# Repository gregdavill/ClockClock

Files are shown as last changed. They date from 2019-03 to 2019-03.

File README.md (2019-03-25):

# ClockClock

## Experiements with stepper based instrument dials to create a digitally controlled Analoge Clock.

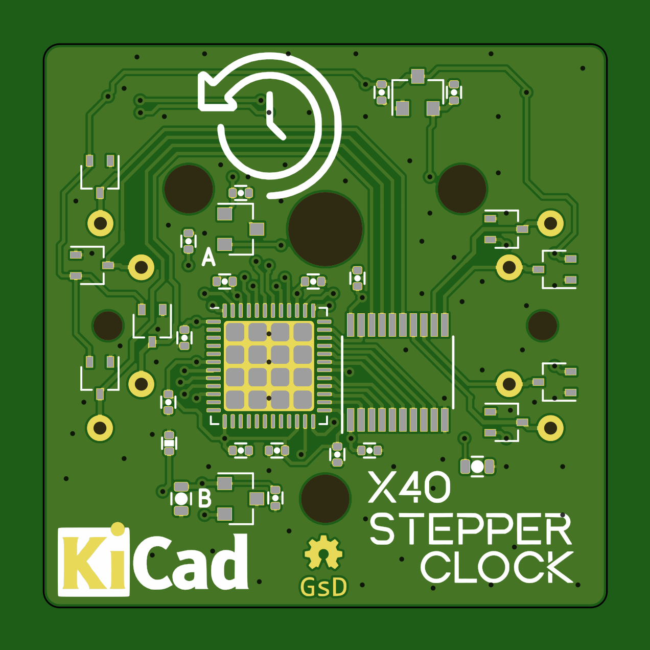
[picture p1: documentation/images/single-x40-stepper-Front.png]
Front View


## Hardware

* MachXo2-640 in QFN48
* Plenty of test pads
* X40 Dual output instument dial stepper (modified for full rotation)
* Hall effect switches for indexing arms on clock
* Flyback diodes on all motor outputs

## Board View

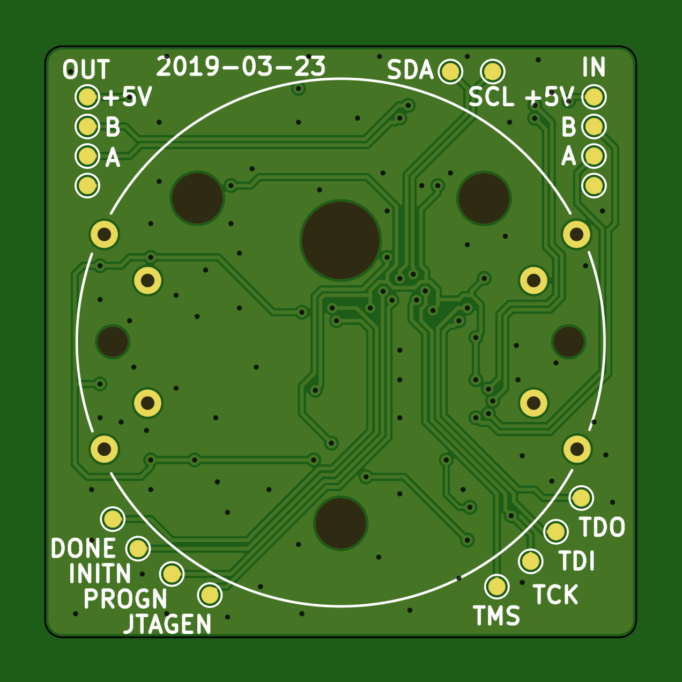
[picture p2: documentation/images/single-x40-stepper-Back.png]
Back View


## Schematic

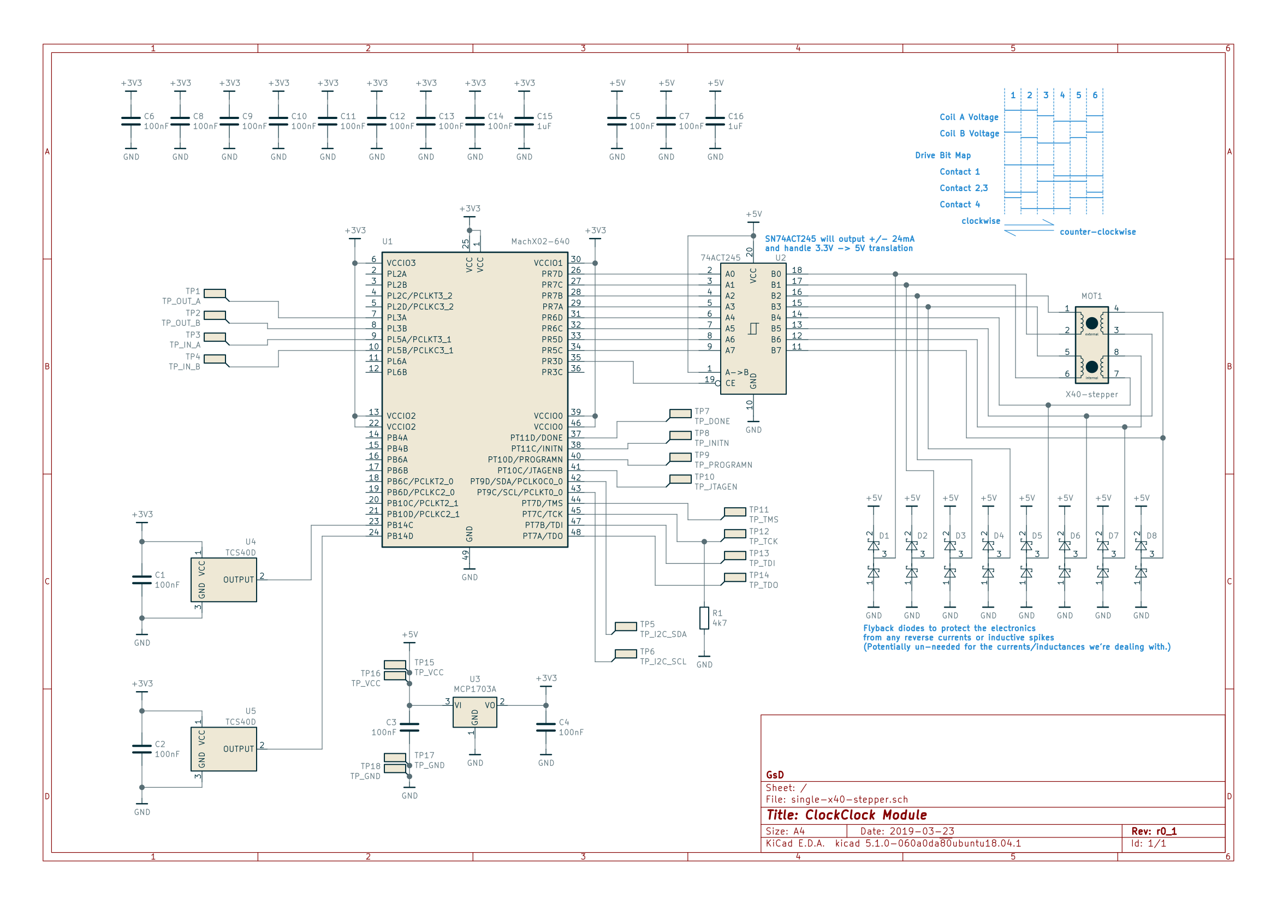
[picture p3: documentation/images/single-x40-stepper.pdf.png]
Schematic


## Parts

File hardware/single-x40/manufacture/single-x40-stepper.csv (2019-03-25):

Source: | /home/greg/projects/ClockClock/hardware/single-x40/single-x40-stepper.sch
Date: | Sat 23 Mar 2019 20:49:43 ACDT
Tool: | Eeschema 5.1.0-060a0da~80~ubuntu18.04.1
Generator: | /usr/share/kicad/plugins/bom_csv_grouped_by_value.py
Component Count: | 31
Individual Components:
Item | Qty | Reference(s) | Value | LibPart | Footprint | Datasheet | Mfg | PN
 |  | C1 | 100nF | Device:C | pkl_dipol:C_0402 | ~ | Samsung Electro-Mechanics | CL05B104KP5NNNC
 |  | C2 | 100nF | Device:C | pkl_dipol:C_0402 | ~ | Samsung Electro-Mechanics | CL05B104KP5NNNC
 |  | C3 | 100nF | Device:C | pkl_dipol:C_0402 | ~ | Samsung Electro-Mechanics | CL05B104KP5NNNC
 |  | C4 | 100nF | Device:C | pkl_dipol:C_0402 | ~ | Samsung Electro-Mechanics | CL05B104KP5NNNC
 |  | C5 | 100nF | Device:C | pkl_dipol:C_0402 | ~ | Samsung Electro-Mechanics | CL05B104KP5NNNC
 |  | C6 | 100nF | Device:C | pkl_dipol:C_0402 | ~ | Samsung Electro-Mechanics | CL05B104KP5NNNC
 |  | C7 | 100nF | Device:C | pkl_dipol:C_0402 | ~ | Samsung Electro-Mechanics | CL05B104KP5NNNC
 |  | C8 | 100nF | Device:C | pkl_dipol:C_0402 | ~ | Samsung Electro-Mechanics | CL05B104KP5NNNC
 |  | C9 | 100nF | Device:C | pkl_dipol:C_0402 | ~ | Samsung Electro-Mechanics | CL05B104KP5NNNC
 |  | C10 | 100nF | Device:C | pkl_dipol:C_0402 | ~ | Samsung Electro-Mechanics | CL05B104KP5NNNC
 |  | C11 | 100nF | Device:C | pkl_dipol:C_0402 | ~ | Samsung Electro-Mechanics | CL05B104KP5NNNC
 |  | C12 | 100nF | Device:C | pkl_dipol:C_0402 | ~ | Samsung Electro-Mechanics | CL05B104KP5NNNC
 |  | C13 | 100nF | Device:C | pkl_dipol:C_0402 | ~ | Samsung Electro-Mechanics | CL05B104KP5NNNC
 |  | C14 | 100nF | Device:C | pkl_dipol:C_0402 | ~ | Samsung Electro-Mechanics | CL05B104KP5NNNC
 |  | C15 | 1uF | Device:C | pkl_dipol:C_0603 | ~ | Samsung Electro-Mechanics | CL10A106MP8NNNC
 |  | C16 | 1uF | Device:C | pkl_dipol:C_0603 | ~ | Samsung Electro-Mechanics | CL10A106MP8NNNC
 |  | D1 | BAT54S | Diode:BAT54S | Package_TO_SOT_SMD:SOT-323_SC-70 | https://www.diodes.com/assets/Datasheets/ds11005.pdf | ON Semiconductor | BAT54SWT1G
 |  | D2 | BAT54S | Diode:BAT54S | Package_TO_SOT_SMD:SOT-323_SC-70 | https://www.diodes.com/assets/Datasheets/ds11005.pdf | ON Semiconductor | BAT54SWT1G
 |  | D3 | BAT54S | Diode:BAT54S | Package_TO_SOT_SMD:SOT-323_SC-70 | https://www.diodes.com/assets/Datasheets/ds11005.pdf | ON Semiconductor | BAT54SWT1G
 |  | D4 | BAT54S | Diode:BAT54S | Package_TO_SOT_SMD:SOT-323_SC-70 | https://www.diodes.com/assets/Datasheets/ds11005.pdf | ON Semiconductor | BAT54SWT1G
 |  | D5 | BAT54S | Diode:BAT54S | Package_TO_SOT_SMD:SOT-323_SC-70 | https://www.diodes.com/assets/Datasheets/ds11005.pdf | ON Semiconductor | BAT54SWT1G
 |  | D6 | BAT54S | Diode:BAT54S | Package_TO_SOT_SMD:SOT-323_SC-70 | https://www.diodes.com/assets/Datasheets/ds11005.pdf | ON Semiconductor | BAT54SWT1G
 |  | D7 | BAT54S | Diode:BAT54S | Package_TO_SOT_SMD:SOT-323_SC-70 | https://www.diodes.com/assets/Datasheets/ds11005.pdf | ON Semiconductor | BAT54SWT1G
 |  | D8 | BAT54S | Diode:BAT54S | Package_TO_SOT_SMD:SOT-323_SC-70 | https://www.diodes.com/assets/Datasheets/ds11005.pdf | ON Semiconductor | BAT54SWT1G
 |  | MOT1 | X40-stepper | gkl_misc:X40-stepper | gkl_misc:X40-stepper
 |  | R1 | 4k7 | Device:R | pkl_dipol:R_0402 | ~ | Stackpole Electronics Inc | RMCF0402FT4K70
 |  | U1 | MachX02-640 | gkl_lattice:MachX02-640 | Package_DFN_QFN:QFN-48-1EP_7x7mm_P0.5mm_EP5.6x5.6mm |  | Lattice Semiconductor Corporation | LCMXO2-640HC-4SG48C
 |  | U2 | 74ACT245 | 74xx:74LS245 | Package_SO:TSSOP-20_4.4x6.5mm_P0.65mm | http://www.ti.com/lit/gpn/sn74LS245 | Texas Instruments | SN74ACT245PWR
 |  | U3 | MCP1703A | Regulator_Linear:MCP1703A-1202_SOT23 | Package_TO_SOT_SMD:SOT-23 | http://ww1.microchip.com/downloads/en/DeviceDoc/20005122B.pdf | Microchip Technology | MCP1703AT-3302E/CB
 |  | U4 | TCS40D | Sensor_Magnetic:SM351LT | Package_TO_SOT_SMD:SOT-23 | https://sensing.honeywell.com/honeywell-sensing-nanopower-series-product-sheet-50095501-a-en.pdf | Toshiba Semiconductor and Storage | TCS40DPR,LF
 |  | U5 | TCS40D | Sensor_Magnetic:SM351LT | Package_TO_SOT_SMD:SOT-23 | https://sensing.honeywell.com/honeywell-sensing-nanopower-series-product-sheet-50095501-a-en.pdf | Toshiba Semiconductor and Storage | TCS40DPR,LF
Collated Components:
Item | Qty | Reference(s) | Value | LibPart | Footprint | Datasheet | Mfg | PN
1 | 14 | C1, C2, C3, C4, C5, C6, C7, C8, C9, C10, C11, C12, C13, C14 | 100nF | Device:C | pkl_dipol:C_0402 | ~ | Samsung Electro-Mechanics | CL05B104KP5NNNC
2 | 2 | C15, C16 | 1uF | Device:C | pkl_dipol:C_0603 | ~ | Samsung Electro-Mechanics | CL10A106MP8NNNC
3 | 8 | D1, D2, D3, D4, D5, D6, D7, D8 | BAT54S | Diode:BAT54S | Package_TO_SOT_SMD:SOT-323_SC-70 | https://www.diodes.com/assets/Datasheets/ds11005.pdf | ON Semiconductor | BAT54SWT1G
4 | 1 | MOT1 | X40-stepper | gkl_misc:X40-stepper | gkl_misc:X40-stepper
5 | 1 | R1 | 4k7 | Device:R | pkl_dipol:R_0402 | ~ | Stackpole Electronics Inc | RMCF0402FT4K70
6 | 1 | U1 | MachX02-640 | gkl_lattice:MachX02-640 | Package_DFN_QFN:QFN-48-1EP_7x7mm_P0.5mm_EP5.6x5.6mm |  | Lattice Semiconductor Corporation | LCMXO2-640HC-4SG48C
7 | 1 | U2 | 74ACT245 | 74xx:74LS245 | Package_SO:TSSOP-20_4.4x6.5mm_P0.65mm | http://www.ti.com/lit/gpn/sn74LS245 | Texas Instruments | SN74ACT245PWR
8 | 1 | U3 | MCP1703A | Regulator_Linear:MCP1703A-1202_SOT23 | Package_TO_SOT_SMD:SOT-23 | http://ww1.microchip.com/downloads/en/DeviceDoc/20005122B.pdf | Microchip Technology | MCP1703AT-3302E/CB
9 | 2 | U4, U5 | TCS40D | Sensor_Magnetic:SM351LT | Package_TO_SOT_SMD:SOT-23 | https://sensing.honeywell.com/honeywell-sensing-nanopower-series-product-sheet-50095501-a-en.pdf | Toshiba Semiconductor and Storage | TCS40DPR,LF

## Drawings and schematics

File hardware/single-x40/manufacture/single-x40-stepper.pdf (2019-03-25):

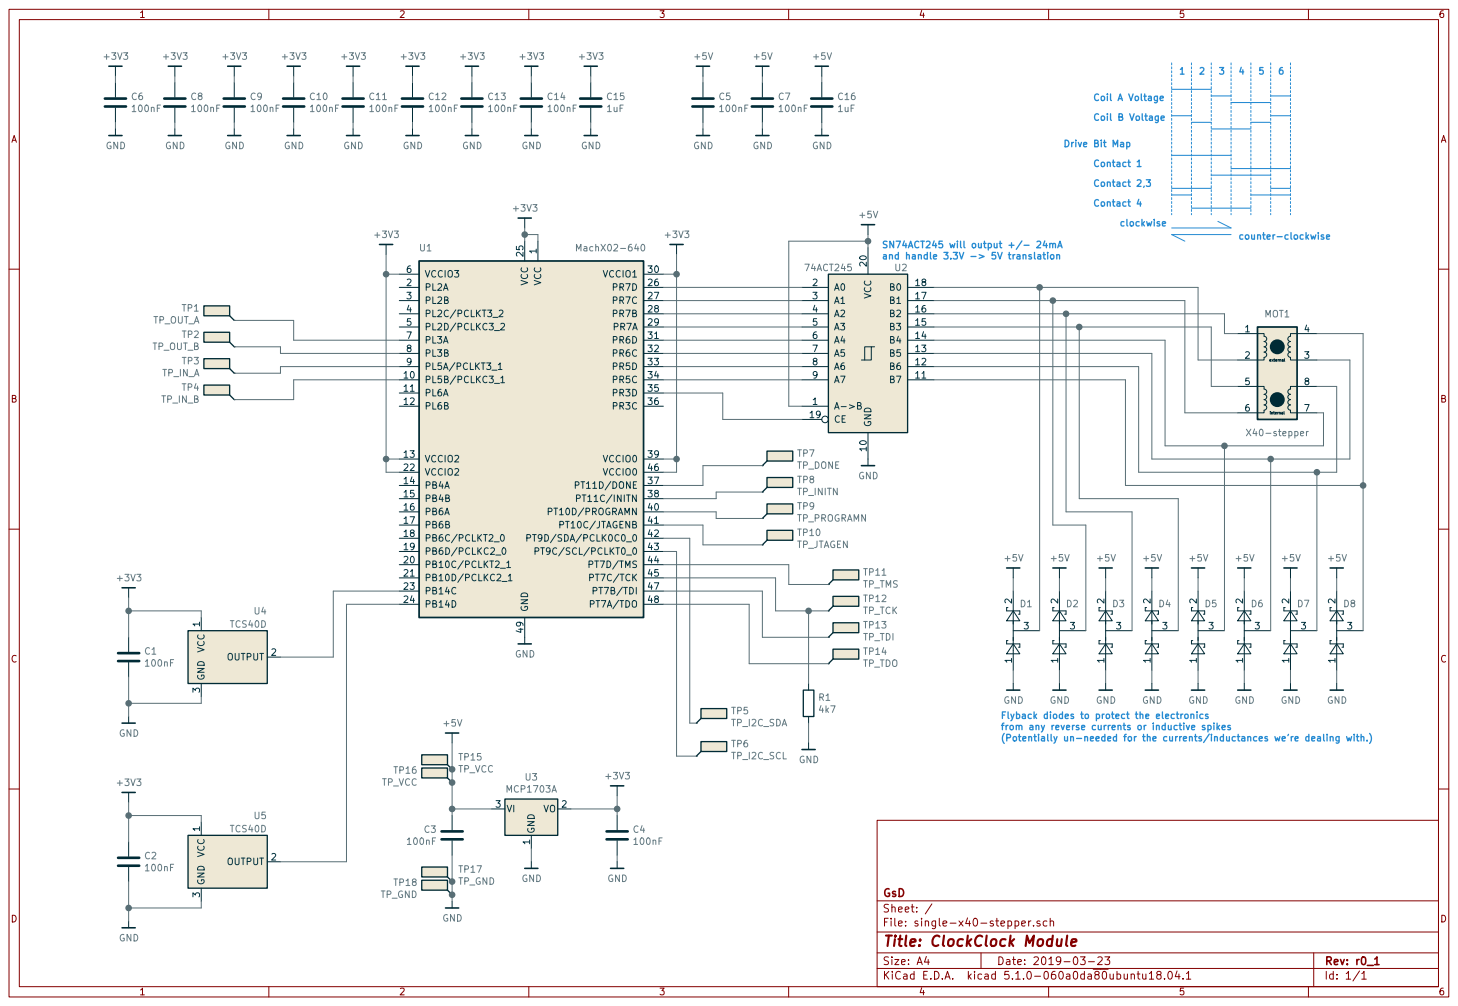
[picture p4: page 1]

Drive Bit Map Contact 1 Contact 2,3 Contact 4

1 PL5B/PCLKC3_1 10 PL6A 11 PL6B 12 VCCIO2 13 PB4A 14 PB4B 15 PB6A 16 PB6B 17 PB6C/PCLKT2_0 18 PB6D/PCLKC2_0 19 PL2A 2 PB10C/PCLKT2_1 20 PB10D/PCLKC2_1 21 VCCIO2 22 PB14C 23 PB14D 24 VCC 25 PR7D 26 PR7C 27 PR7B 28 PR7A 29 PL2B 3 VCCIO1 30 PR6D 31 PR6C 32 PR5D 33 PR5C 34 PR3D 35 PR3C 36 PT11D/DONE 37 PT11C/INITN 38 VCCIO0 39 PL2C/PCLKT3_2 4 PT10D/PROGRAMN 40 PT10C/JTAGENB 41 PT9D/SDA/PCLK0C0_0 42 PT9C/SCL/PCLKT0_0 43 PT7D/TMS 44 PT7C/TCK 45 VCCIO0 46 PT7B/TDI 47 PT7A/TDO 48 GND 49 PL2D/PCLKC3_2 5 VCCIO3 6 PL3A 7 PL3B 8 PL5A/PCLKT3_1 9 U1 MachX02-640 A->B 1 GND 10 B7 11 B6 12 B5 13 B4 14 B3 15 B2 16 B1 17 B0 18 CE 19 A0 2 VCC 20 A1 3 A2 4 A3 5 A4 6 A5 7 A6 8 A7 9

File: single-x40-stepper.sch Sheet: / GsD VCC

(Potentially un-needed for the currents/inductances we're dealing with.) GND

Flyback diodes to protect the electronics
from any reverse currents or inductive spikes

Id: 1/1 Title: ClockClock Module

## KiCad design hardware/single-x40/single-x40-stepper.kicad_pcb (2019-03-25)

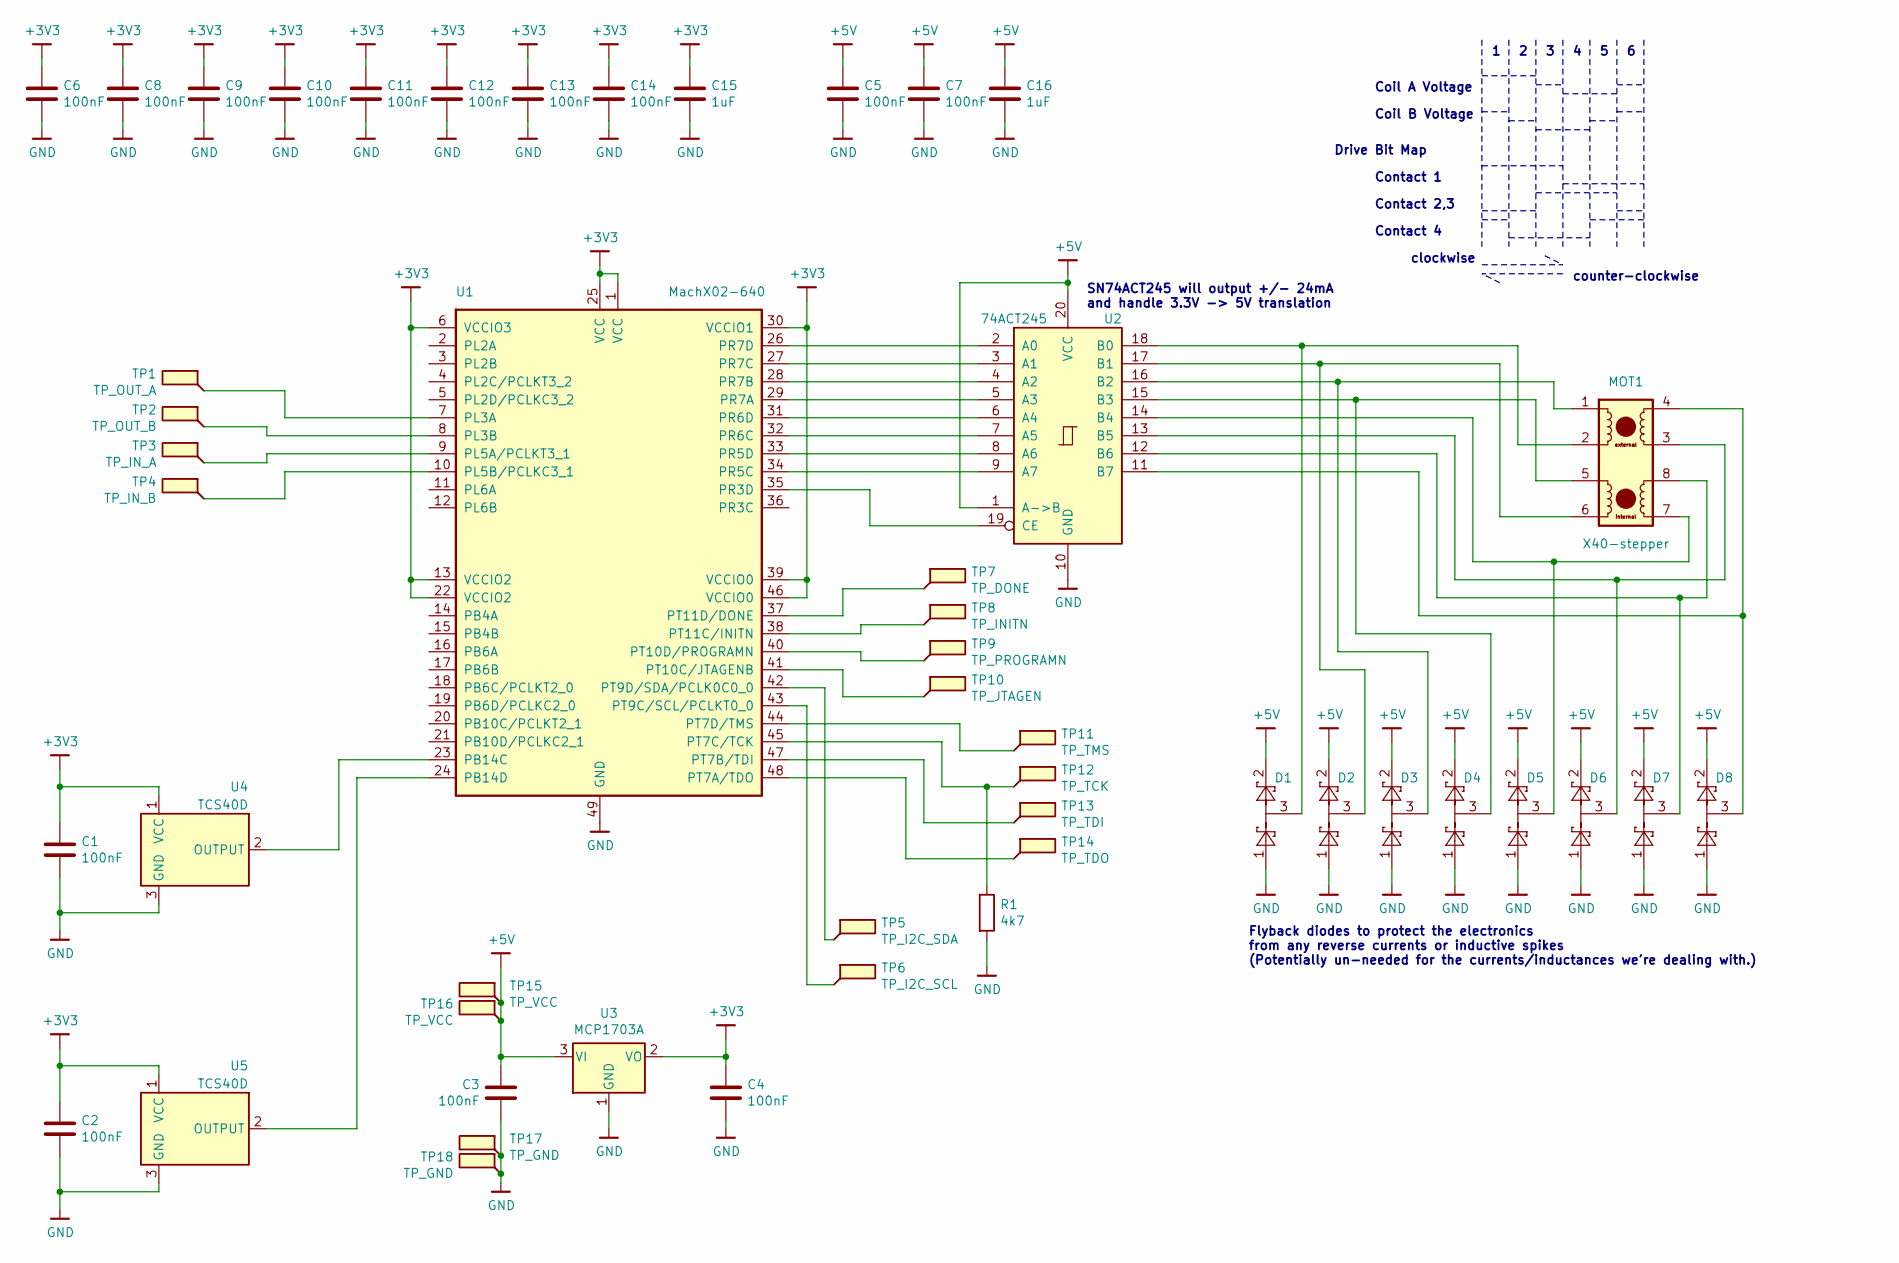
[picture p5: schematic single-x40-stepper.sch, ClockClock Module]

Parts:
C1, C2, C3, C4, C5, C6, C7, C8, C9, C10, C11, C12, C13, C14: 100nF; C_0402
C15, C16: 1uF; C_0603
D1, D2, D3, D4, D5, D6, D7, D8: BAT54S; SOT-323_SC-70
MOT1: X40-stepper
R1: 4k7; R_0402
TP1: TP_OUT_A; TestPoint_Pad_D1.0mm
TP2: TP_OUT_B; TestPoint_Pad_D1.0mm
TP3: TP_IN_A; TestPoint_Pad_D1.0mm
TP4: TP_IN_B; TestPoint_Pad_D1.0mm
TP5: TP_I2C_SDA; TestPoint_Pad_D1.0mm
TP6: TP_I2C_SCL; TestPoint_Pad_D1.0mm
TP7: TP_DONE; TestPoint_Pad_D1.0mm
TP8: TP_INITN; TestPoint_Pad_D1.0mm
TP9: TP_PROGRAMN; TestPoint_Pad_D1.0mm
TP10: TP_JTAGEN; TestPoint_Pad_D1.0mm
TP11: TP_TMS; TestPoint_Pad_D1.0mm
TP12: TP_TCK; TestPoint_Pad_D1.0mm
TP13: TP_TDI; TestPoint_Pad_D1.0mm
TP14: TP_TDO; TestPoint_Pad_D1.0mm
TP15, TP16: TP_VCC; TestPoint_Pad_D1.0mm
TP17, TP18: TP_GND; TestPoint_Pad_D1.0mm
U1: MachX02-640; QFN-48-1EP_7x7mm_P0.5mm_EP5.6x5.6mm
U2: 74ACT245; TSSOP-20_4.4x6.5mm_P0.65mm
U3: MCP1703A; SOT-23
U4, U5: TCS40D; SOT-23

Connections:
+3V3: C1.1, C2.1, C4.1, C6.1, C8.1, C9.1, C10.1, C11.1, C12.1, C13.1, C14.1, C15.1, U1.1 (VCC), U1.6 (VCCIO3), U1.13 (VCCIO2), U1.22 (VCCIO2), U1.25 (VCC), U1.30 (VCCIO1), U1.39 (VCCIO0), U1.46 (VCCIO0), U3.2 (VO), U4.1 (VCC), U5.1 (VCC)
+5V: C3.1, C5.1, C7.1, C16.1, D1.2, D2.2, D3.2, D4.2, D5.2, D6.2, D7.2, D8.2, TP15.1, TP16.1, U2.1 (A->B), U2.20 (VCC), U3.3 (VI)
GND: C1.2, C2.2, C3.2, C4.2, C5.2, C6.2, C7.2, C8.2, C9.2, C10.2, C11.2, C12.2, C13.2, C14.2, C15.2, C16.2, D1.1, D2.1, D3.1, D4.1, D5.1, D6.1, D7.1, D8.1, R1.2, TP17.1, TP18.1, U1.49 (GND), U2.10 (GND), U3.1 (GND), U4.3 (GND), U5.3 (GND)
unnamed: D1.3, MOT1.2, U2.18 (B0)
unnamed: D2.3, MOT1.6, U2.17 (B1)
unnamed: D3.3, MOT1.1, U2.16 (B2)
unnamed: D4.3, MOT1.5, U2.15 (B3)
unnamed: D5.3, MOT1.7, U2.14 (B4)
unnamed: D6.3, MOT1.3, U2.13 (B5)
unnamed: D7.3, MOT1.8, U2.12 (B6)
unnamed: D8.3, MOT1.4, U2.11 (B7)
unnamed: R1.1, TP12.1, U1.45 (PT7C/TCK)
unnamed: TP1.1, U1.7 (PL3A)
unnamed: TP2.1, U1.8 (PL3B)
unnamed: TP3.1, U1.9 (PL5A/PCLKT3_1)
unnamed: TP4.1, U1.10 (PL5B/PCLKC3_1)
unnamed: TP5.1, U1.42 (PT9D/SDA/PCLK0C0_0)
unnamed: TP6.1, U1.43 (PT9C/SCL/PCLKT0_0)
unnamed: TP7.1, U1.37 (PT11D/DONE)
unnamed: TP8.1, U1.38 (PT11C/INITN)
unnamed: TP9.1, U1.40 (PT10D/PROGRAMN)
unnamed: TP10.1, U1.41 (PT10C/JTAGENB)
unnamed: TP11.1, U1.44 (PT7D/TMS)
unnamed: TP13.1, U1.47 (PT7B/TDI)
unnamed: TP14.1, U1.48 (PT7A/TDO)
unnamed: U1.23 (PB14C), U4.2 (OUTPUT)
unnamed: U1.24 (PB14D), U5.2 (OUTPUT)
unnamed: U1.26 (PR7D), U2.2 (A0)
unnamed: U1.27 (PR7C), U2.3 (A1)
unnamed: U1.28 (PR7B), U2.4 (A2)
unnamed: U1.29 (PR7A), U2.5 (A3)
unnamed: U1.31 (PR6D), U2.6 (A4)
unnamed: U1.32 (PR6C), U2.7 (A5)
unnamed: U1.33 (PR5D), U2.8 (A6)
unnamed: U1.34 (PR5C), U2.9 (A7)
unnamed: U1.35 (PR3D), U2.19 (CE)

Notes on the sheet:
Coil A Voltage
Coil B Voltage
Drive Bit Map
Contact 1
Contact 2,3
Contact 4
SN74ACT245 will output +/- 24mA and handle 3.3V -> 5V translation
clockwise
counter-clockwise
Flyback diodes to protect the electronics from any reverse currents or inductive spikes (Potentially un-needed for the currents/inductances we're dealing with.)

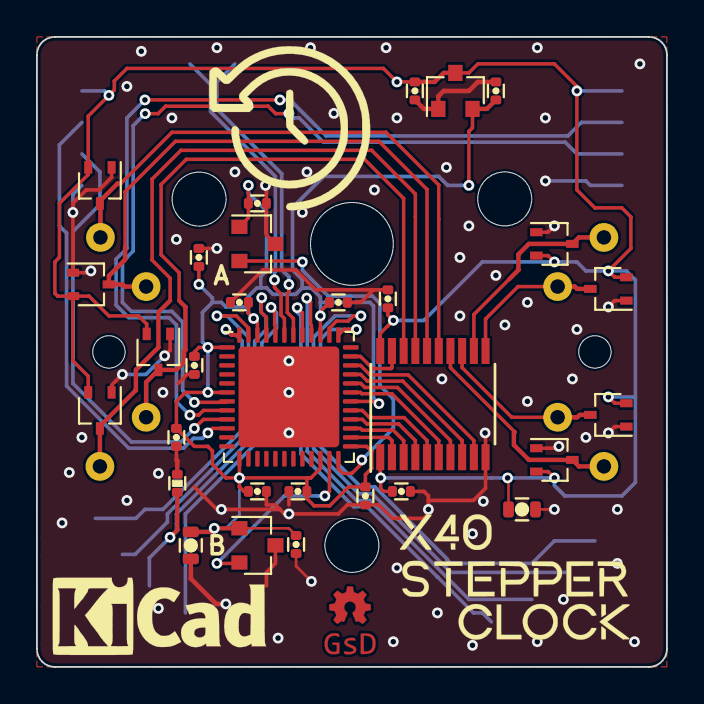
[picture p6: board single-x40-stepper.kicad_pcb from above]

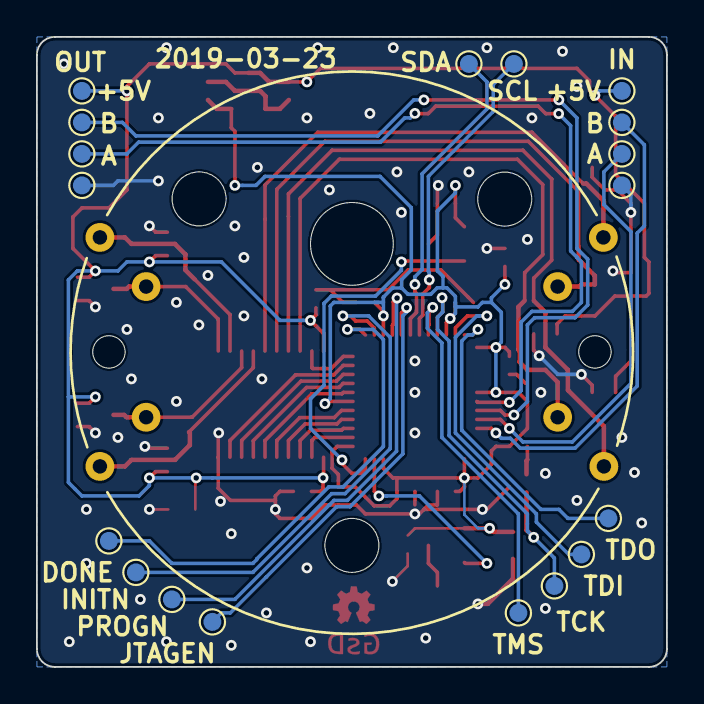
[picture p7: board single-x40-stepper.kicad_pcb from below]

Board: 2 copper layers, 35.0 x 35.0 mm, 49 parts (18 on the bottom side), 36 nets.
